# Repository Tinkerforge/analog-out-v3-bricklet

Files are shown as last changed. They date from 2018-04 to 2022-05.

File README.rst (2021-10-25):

Analog Out Bricklet 3.0
=======================

This repository contains the firmware source code and the hardware design
files. The documentation generator configs can be found at
https://github.com/Tinkerforge/generators

Repository Content
------------------

software/:
 * examples/: Examples for all supported languages
 * build/: Compiled files
 * src/: Source code of firmware
 * Makefile: Makefile to build project

hardware/:
 * Contains KiCad project files and additionally schematics as PDF

datasheets/:
 * Contains datasheets for sensors and complex ICs that are used

Hardware
--------

The hardware is designed with the open source EDA Suite KiCad
(http://www.kicad.org). Before you are able to open the files,
you have to install the Tinkerforge kicad-libraries
(https://github.com/Tinkerforge/kicad-libraries). You can either clone
them directly in hardware/ or clone them in a separate folder and
symlink them into hardware/
(ln -s kicad_path/kicad-libraries project_path/hardware). After that you
can open the .pro file in hardware/ with KiCad and from there view and
modify the schematics and the PCB layout.

Software
--------

If you want to do your own Brick/Bricklet firmware development we highly
recommend that you use our build environment setup script and read the
tutorial (https://www.tinkerforge.com/en/doc/Tutorials/Tutorial_Build_Environment/Tutorial.html).

To compile the C code we recommend you to install the newest GNU Arm Embedded
Toolchain (https://launchpad.net/gcc-arm-embedded/+download).
You also need to install bricklib2 (https://github.com/Tinkerforge/bricklib2).

You can either clone it directly in software/src/ or clone it in a
separate folder and symlink it into software/src/
(ln -s bricklib_path/bricklib2 project_path/software/src/). Finally make sure to
have CMake installed (http://www.cmake.org/cmake/resources/software.html).

After that you can build the firmware by invoking make in software/.
The firmware (.zbin) can then be found in software/build/ and uploaded
with brickv (click button "Flashing" on start screen).

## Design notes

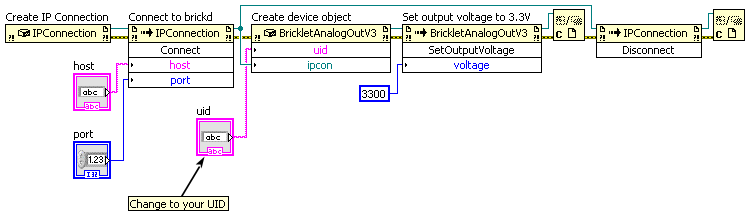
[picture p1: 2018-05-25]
software/examples/labview/Example Simple.vi.png

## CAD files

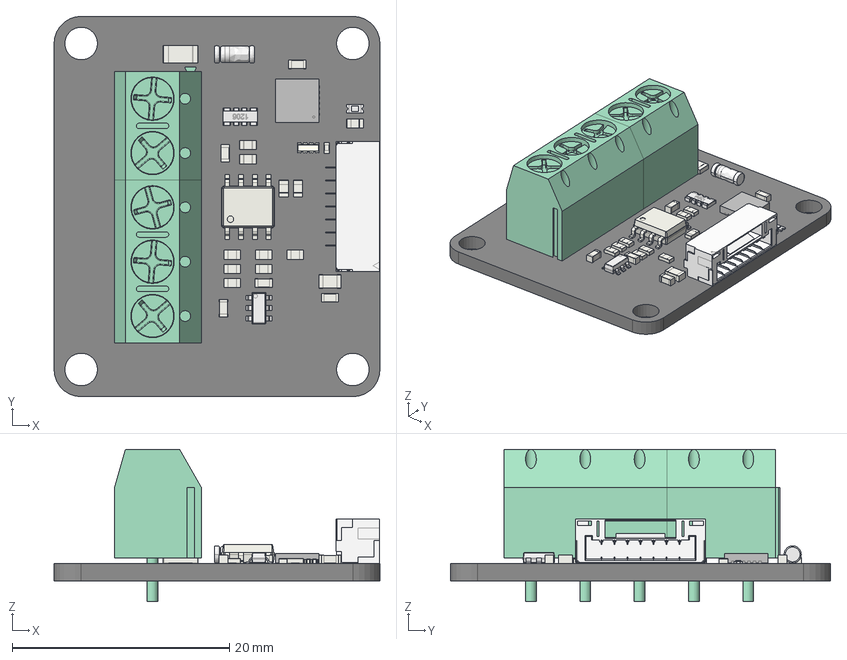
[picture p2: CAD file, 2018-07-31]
hardware/analog-out-v3.FCStd
30.0 x 35.0 x 14.0 mm
Pcb
QFN-24_4x4mm_Pitch0.5mm_
R_0603_
BrickletConn_7pin_
D_0603_blue_
R_0603_001
R_0603_002
R_0603_003
R_0603_004
R_0603_005
R_0603_006
R_0603_007
R_0603_008
R_0603_009
R_0603_010
C_0603_
C_0603_001
C_0603_002
C_0805_
C_0603_003
C_0603_004
soic_8_39x49_p127_
MiniMelf_
F_1206_
R_4x0603_
C_0402_

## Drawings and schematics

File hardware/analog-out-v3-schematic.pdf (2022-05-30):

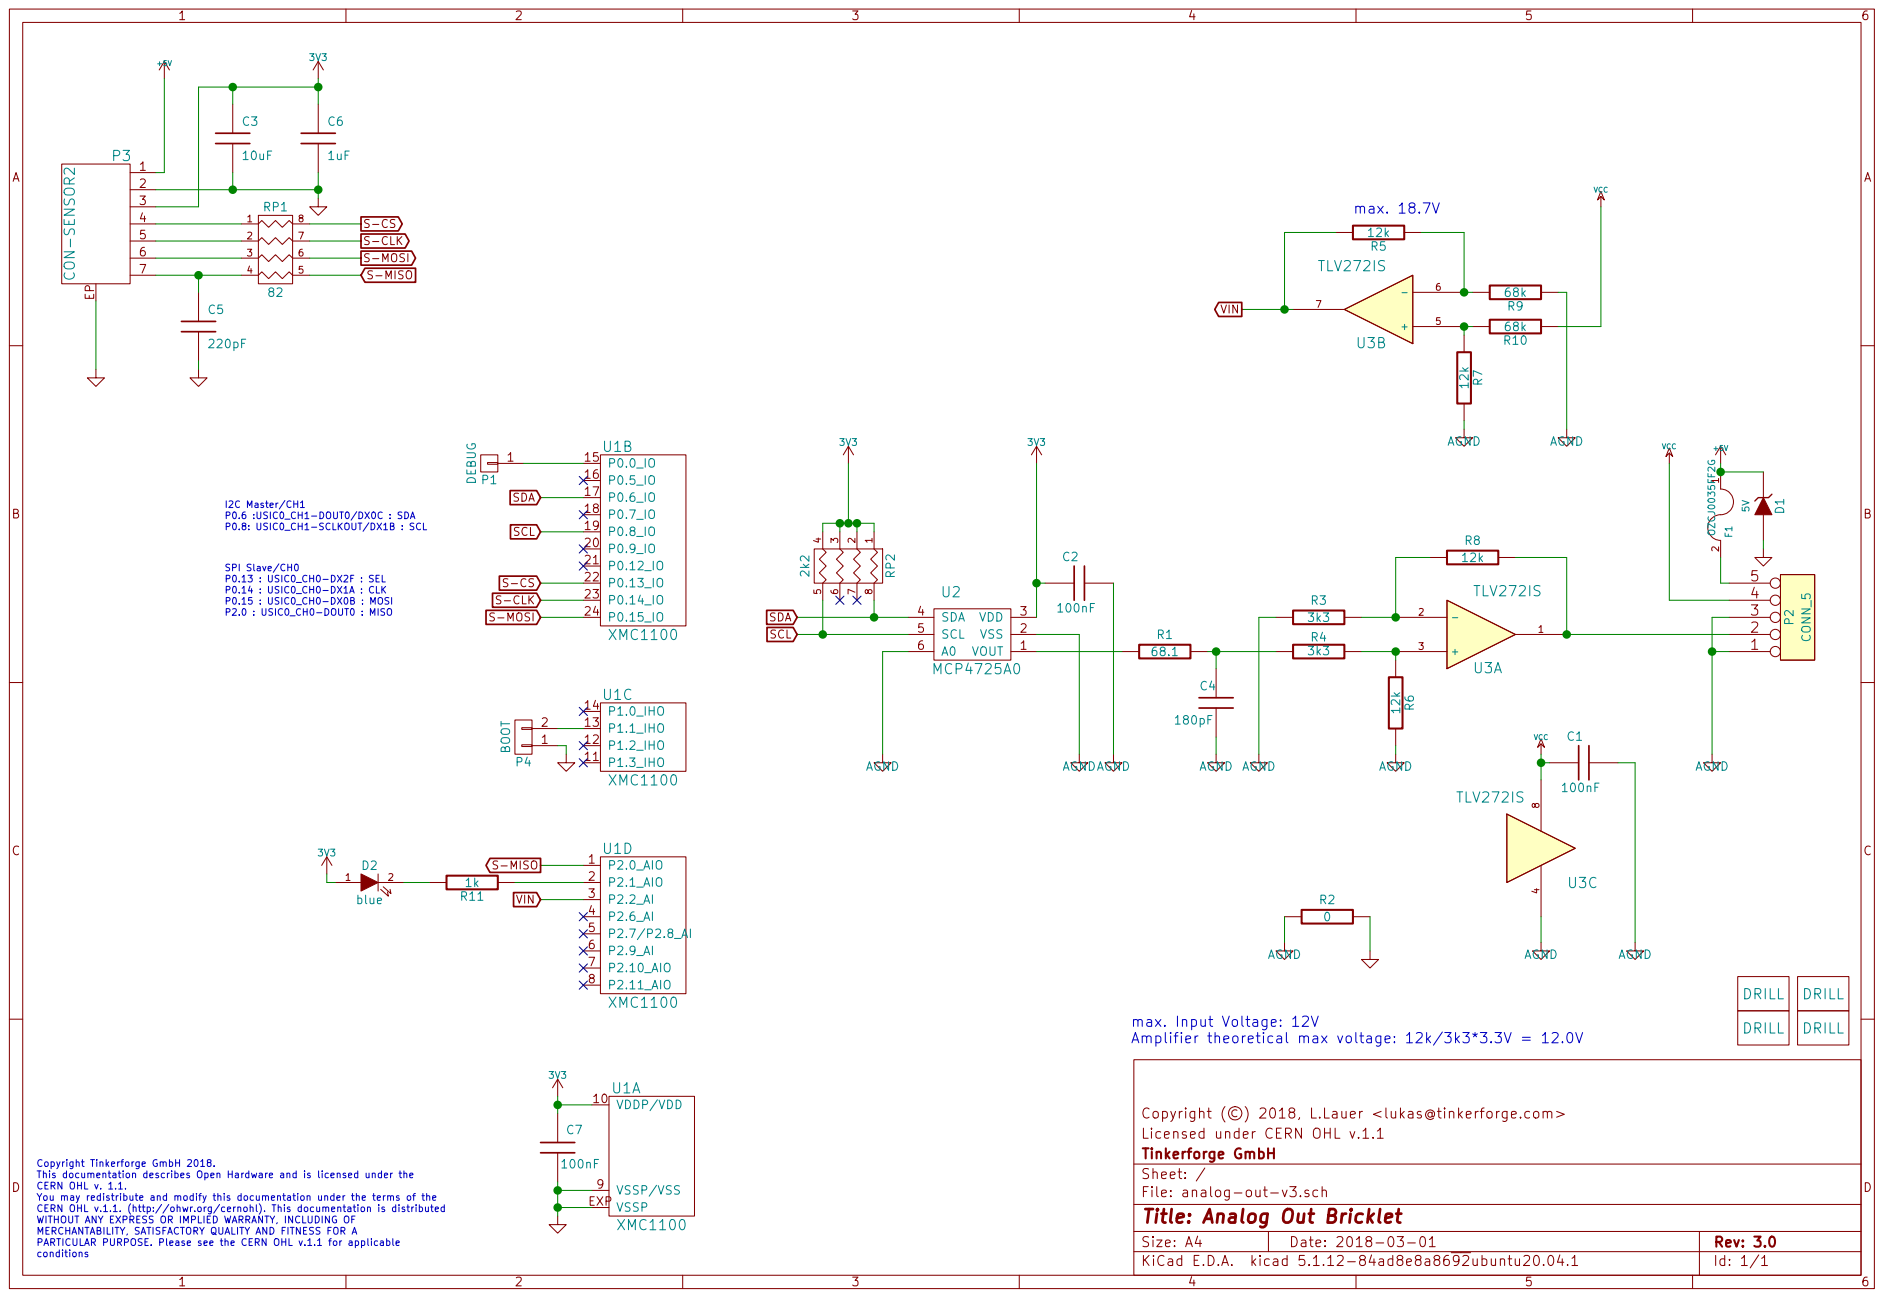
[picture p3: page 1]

SPI Slave/CH0 P0.13 : USIC0_CH0-DX2F : SEL P0.14 : USIC0_CH0-DX1A : CLK

Amplifier theoretical max voltage: 12k/3k3*3.3V = 12.0V

Licensed under CERN OHL v.1.1 Copyright (©) 2018, L.Lauer <lukas@tinkerforge.com>

File: analog-out-v3.sch Sheet: / Tinkerforge GmbH

Copyright Tinkerforge GmbH 2018. This documentation describes Open Hardware and is licensed under the CERN OHL v. 1.1. You may redistribute and modify this documentation under the terms of the CERN OHL v.1.1. (http://ohwr.org/cernohl). This documentation is distributed WITHOUT ANY EXPRESS OR IMPLIED WARRANTY, INCLUDING OF MERCHANTABILITY, SATISFACTORY QUALITY AND FITNESS FOR A

Id: 1/1 Title: Analog Out Bricklet

PARTICULAR PURPOSE. Please see the CERN OHL v.1.1 for applicable
conditions

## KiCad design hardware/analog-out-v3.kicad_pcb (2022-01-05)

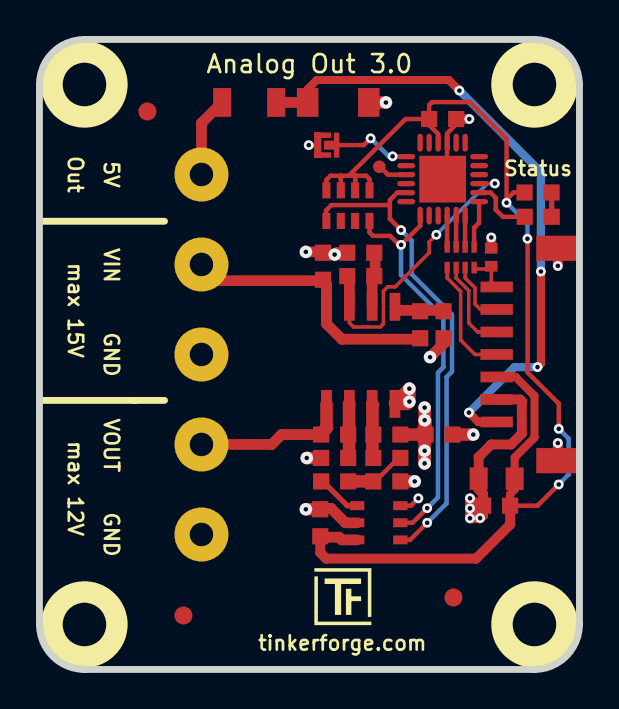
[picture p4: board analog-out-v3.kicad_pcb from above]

Board: 2 copper layers, 30.0 x 35.0 mm, 40 parts (0 on the bottom side), 28 nets.

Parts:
C1, C2, C7: 100nF; C0603F
C3: 10uF; C0805
C4: 180pF; C0603F
C5: 220pF; C0402F
C6: 1uF; C0603F
D1: 5V; MiniMelf
D2: blue; D0603F
F1: OZCJ0035FF2G; F1206
Fiducial_Mark: VAL**; Fiducial_Mark
Fiducial_Mark#2, Fiducial_Mark#3: VAL**; Fiducial_Mark
P1: DEBUG; DEBUG_PAD
P2: CONN_5; AKL_5_5
P3: CON-SENSOR2
P4: BOOT; SolderJumper
R1: 68.1; R0603F
R2: 0; R0603F
R3, R4: 3k3; R0603F
R5, R6, R7, R8: 12k; R0603F
R9, R10: 68k; R0603F
R11: 1k; R0603F
RP1: 82; 4X0402
RP2: 2k2; 4X0603
Ref**: Val**; Logo_31x31
U1: XMC1100; QFN24-4x4mm-0.5mm
U2: MCP4725A0; SOT23-6
U3: TLV272IS; SOIC8
U4, U5, U6, U7: DRILL; DRILL_NP
VAL: CE_5mm
VAL#2: WEEE_7mm

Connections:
3V3: C2.1, C3.1, C6.1, C7.2, D2.1, P3.3, RP2.1, RP2.2, RP2.3, RP2.4, U1.10, U2.3
+5V: D1.2, F1.1, P3.1
AGND: C1.2, C2.2, C4.2, P2.1, P2.3, R2.2, R3.2, R6.2, R7.2, R9.1, U2.2, U2.6, U3.4
GND: C3.2, C5.2, C6.2, C7.1, D1.1, P3.2, P3.EP, P4.1, R2.1, U1.9, U1.EXP
unnamed: C4.1, R1.1, R4.1
unnamed: C5.1, P3.7, RP1.4
unnamed: D2.2, R11.2
unnamed: F1.2, P2.5
unnamed: P1.1, U1.15
unnamed: P2.2, R8.1, U3.1
unnamed: P3.4, RP1.1
unnamed: P3.5, RP1.2
unnamed: P3.6, RP1.3
unnamed: P4.2, U1.13
unnamed: R1.2, U2.1
unnamed: R3.1, R8.2, U3.2
unnamed: R4.2, R6.1, U3.3
unnamed: R5.1, R9.2, U3.6
unnamed: R7.1, R10.2, U3.5
unnamed: R11.1, U1.2
S-CLK: RP1.7, U1.23
S-CS: RP1.8, U1.22
S-MISO: RP1.5, U1.1
S-MOSI: RP1.6, U1.24
SCL: RP2.5, U1.19, U2.5
SDA: RP2.8, U1.17, U2.4
VCC: C1.1, P2.4, R10.1, U3.8
VIN: R5.2, U1.3, U3.7

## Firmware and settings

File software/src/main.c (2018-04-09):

/* analog-out-v3-bricklet
 * Copyright (C) 2018 Olaf Lüke <olaf@tinkerforge.com>
 *
 * main.c: Initialization for Analog Out V3 Bricklet
 *
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
 * You should have received a copy of the GNU Lesser General Public
 * License along with this library; if not, write to the
 * Free Software Foundation, Inc., 59 Temple Place - Suite 330,
 * Boston, MA 02111-1307, USA.
 */

#include <stdio.h>
#include <stdbool.h>

#include "configs/config.h"

#include "bricklib2/bootloader/bootloader.h"
#include "bricklib2/hal/system_timer/system_timer.h"
#include "bricklib2/logging/logging.h"
#include "communication.h"

int main(void) {
	logging_init();
	logd("Start Analog Out V3 Bricklet\n\r");

	communication_init();

	while(true) {
		bootloader_tick();
		communication_tick();
	}
}

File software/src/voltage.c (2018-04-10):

/* analog-out-v3-bricklet
 * Copyright (C) 2018 Olaf Lüke <olaf@tinkerforge.com>
 *
 * voltage.c: Calculate voltage from ADC
 *
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
 * You should have received a copy of the GNU Lesser General Public
 * License along with this library; if not, write to the
 * Free Software Foundation, Inc., 59 Temple Place - Suite 330,
 * Boston, MA 02111-1307, USA.
 */

#include "voltage.h"

#include <string.h>

#include "configs/config.h"
#include "configs/config_voltage.h"

#include "xmc_vadc.h"
#include "xmc_gpio.h"

#include "communication.h"

#include "bricklib2/hal/system_timer/system_timer.h"
#include "bricklib2/utility/util_definitions.h"

#define VOLTAGE_BUFFER_SIZE 1024
#define VOLTAGE_BUFFER_MASK (VOLTAGE_BUFFER_SIZE-1)

#define voltage_adc_irq_handler IRQ_Hdlr_15
#define ANALOG_IN_V3_OVERSAMPLING_32 0
#define ANALOG_IN_V3_OVERSAMPLING_64 1
#define ANALOG_IN_V3_OVERSAMPLING_128 2
#define ANALOG_IN_V3_OVERSAMPLING_256 3
#define ANALOG_IN_V3_OVERSAMPLING_512 4
#define ANALOG_IN_V3_OVERSAMPLING_1024 5
#define ANALOG_IN_V3_OVERSAMPLING_2048 6
#define ANALOG_IN_V3_OVERSAMPLING_4096 7
#define ANALOG_IN_V3_OVERSAMPLING_8192 8
#define ANALOG_IN_V3_OVERSAMPLING_16384 9

// Keep the variables that are used in the interrupts as simple global variables,
// to be sure that the compiler does not need to do any derefernciation or similar.
static uint16_t voltage_buffer[VOLTAGE_BUFFER_SIZE];
static volatile uint32_t voltage_buffer_index = 0;
static uint32_t voltage_sum = 0;

void __attribute__((optimize("-O3"))) __attribute__ ((section (".ram_code"))) voltage_adc_irq_handler(void) {
	// Remove oldest value from moving average
	voltage_sum -= voltage_buffer[voltage_buffer_index];

	// Save new value to buffer and add it to moving average
	const uint16_t new_value = VADC->GLOBRES & 0xFFFF;
	voltage_buffer[voltage_buffer_index] = new_value;
	voltage_sum += new_value;

	// Increase index
	voltage_buffer_index = (voltage_buffer_index + 1) & VOLTAGE_BUFFER_MASK;
}

void voltage_init_adc(void) {
	// This structure contains the Global related Configuration.
	const XMC_VADC_GLOBAL_CONFIG_t adc_global_config = {
		.boundary0 = (uint32_t) 0, // Lower boundary value for Normal comparison mode
		.boundary1 = (uint32_t) 0, // Upper boundary value for Normal comparison mode

		.class0 = {
			.sample_time_std_conv     = 31,                      // The Sample time is (2*tadci)
			.conversion_mode_standard = XMC_VADC_CONVMODE_12BIT, // 12bit conversion Selected

		},
		.class1 = {
			.sample_time_std_conv     = 31,                      // The Sample time is (2*tadci)
			.conversion_mode_standard = XMC_VADC_CONVMODE_12BIT, // 12bit conversion Selected

		},

		.data_reduction_control         = 0b11, // Accumulate 4 result values
		.wait_for_read_mode             = 0, // GLOBRES Register will not be overwritten until the previous value is read
		.event_gen_enable               = 1, // Result Event from GLOBRES is enabled
		.disable_sleep_mode_control     = 0  // Sleep mode is enabled
	};


	// Global iclass0 configuration
	const XMC_VADC_GLOBAL_CLASS_t adc_global_iclass_config = {
		.conversion_mode_standard = XMC_VADC_CONVMODE_12BIT,
		.sample_time_std_conv	  = 31,
	};

	// Global Result Register configuration structure
	XMC_VADC_RESULT_CONFIG_t adc_global_result_config = {
		.data_reduction_control = 0b11, // Accumulate 4 result values
		.post_processing_mode   = XMC_VADC_DMM_REDUCTION_MODE,
		.wait_for_read_mode  	= 1, // Enabled
		.part_of_fifo       	= 0, // No FIFO
		.event_gen_enable   	= 1  // Enable Result event
	};

	// LLD Background Scan Init Structure
	const XMC_VADC_BACKGROUND_CONFIG_t adc_background_config = {
		.conv_start_mode   = XMC_VADC_STARTMODE_CIR,       // Conversion start mode selected as cancel inject repeat
		.req_src_priority  = XMC_VADC_GROUP_RS_PRIORITY_1, // Priority of the Background request source in the VADC module
		.trigger_signal    = XMC_VADC_REQ_TR_A,            // If Trigger needed then this denotes the Trigger signal
		.trigger_edge      = XMC_VADC_TRIGGER_EDGE_NONE,   // If Trigger needed then this denotes Trigger edge selected
		.gate_signal       = XMC_VADC_REQ_GT_A,			   // If Gating needed then this denotes the Gating signal
		.timer_mode        = 0,							   // Timer Mode Disabled
		.external_trigger  = 0,                            // Trigger is Disabled
		.req_src_interrupt = 0,                            // Background Request source interrupt Disabled
		.enable_auto_scan  = 1,
		.load_mode         = XMC_VADC_SCAN_LOAD_OVERWRITE
	};


	XMC_VADC_GLOBAL_Init(VADC, &adc_global_config);
	XMC_VADC_GLOBAL_StartupCalibration(VADC);

	// Initialize the Global Conversion class 0
	XMC_VADC_GLOBAL_InputClassInit(VADC, adc_global_iclass_config, XMC_VADC_GROUP_CONV_STD, 0);
	// Initialize the Global Conversion class 1
	XMC_VADC_GLOBAL_InputClassInit(VADC, adc_global_iclass_config, XMC_VADC_GROUP_CONV_STD, 1);

	// Initialize the Background Scan hardware
	XMC_VADC_GLOBAL_BackgroundInit(VADC, &adc_background_config);

	// Initialize the global result register
	XMC_VADC_GLOBAL_ResultInit(VADC, &adc_global_result_config);

	XMC_VADC_GLOBAL_BackgroundAddChannelToSequence(VADC, 0, VOLTAGE_ADC_CHANNEL);
	XMC_VADC_GLOBAL_SetResultEventInterruptNode(VADC, XMC_VADC_SR_SHARED_SR0);

	XMC_VADC_GLOBAL_BackgroundTriggerConversion(VADC);

    NVIC_SetPriority(VOLTAGE_ADC_IRQ, VOLTAGE_ADC_IRQ_PRIORITY);
    NVIC_EnableIRQ(VOLTAGE_ADC_IRQ);
}

void voltage_init(void) {
	const XMC_GPIO_CONFIG_t voltage_pin_config = {
		.mode             = XMC_GPIO_MODE_INPUT_TRISTATE,
		.input_hysteresis = XMC_GPIO_INPUT_HYSTERESIS_LARGE,
	};
	XMC_GPIO_Init(VOLTAGE_ADC_PIN, &voltage_pin_config);

	voltage_init_adc();

	// Wait for first adc data to arrive and fill buffer with value.
	// Otherwise it would take ~50ms until we get meaningful data.
	while(voltage_buffer_index == 0);
	NVIC_DisableIRQ(VOLTAGE_ADC_IRQ);
	for(uint16_t i = 1; i < VOLTAGE_BUFFER_SIZE; i++) {
		voltage_buffer[i] = voltage_buffer[0];
	}
	voltage_sum = voltage_buffer[0]*VOLTAGE_BUFFER_SIZE;

	NVIC_EnableIRQ(VOLTAGE_ADC_IRQ);
}

uint16_t voltage_get_voltage(void) {
	//const uint32_t value = (voltage_sum*55ULL)/(21*VOLTAGE_BUFFER_SIZE);
	// Conversion is done by voltage_sum*3300*68/(4095*12*4*VOLTAGE_BUFFER_SIZE);
	// Which is 935/838656. A multiplier of 935 results in an overflow, 
	// we use 187/167731 instead. The difference is irrelevant (1.3*10^-9).
	const uint32_t value = (((uint64_t)voltage_sum)*187)/167731;

	// We never return negative or out-of-bounds values
	return BETWEEN(0, value, UINT16_MAX);
}

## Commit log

2018-03-01 Add initial schematic
    [analog-out.sch]
2018-03-01 Add layout
    [analog-out.kicad_pcb, analog-out.sch]
2018-03-13 Add fiducials
    [analog-out.kicad_pcb]
2018-04-09 Add auto-generated stub firmware for Analog Out 3.0
    [cmake_config_custom.txt]
2018-04-10 fix VIN routing, change LED pin
    [analog-out.kicad_pcb, analog-out.sch]
2018-04-10 Add configs for MCP4725 and voltage measurement
2018-04-17 Remove timeout handling (now directly done in I2CFifo)
2018-05-11 Rename files
    [analog-out-v3.kicad_pcb, analog-out-v3.sch]
2018-06-06 pullup 4k7->2k2, fix origin, fix logos
    [analog-out-v3.kicad_pcb, analog-out-v3.sch]
2018-06-18 Change capacitor footprint(s) to C0402F
    [analog-out-v3.kicad_pcb, analog-out-v3.sch]
2018-07-17 specify processor
    [analog-out-v3.kicad_pcb, analog-out-v3.sch]
2018-07-31 Add 3d model (*.FCStd & *.step)
    [analog-out-v3.FCStd]
2018-07-31 Add PDF schematic
2020-09-02 uc: Add example driver note.
2021-10-25 Update KiCad link
    https://www.kicad.org/blog/2021/10/Avoid-links-to-former-kicad-domain/
2022-01-05 specify processor as XMC1100
    [analog-out-v3.kicad_pcb, analog-out-v3.sch]
2022-05-30 fix schematic
    [analog-out-v3.sch]

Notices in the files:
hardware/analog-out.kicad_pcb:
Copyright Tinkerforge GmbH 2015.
